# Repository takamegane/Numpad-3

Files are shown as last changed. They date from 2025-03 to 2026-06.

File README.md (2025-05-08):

# Numpad-3
 
## 必要なパーツ
* RP2040 zero x1  
* 1N4148W SMDダイオード x22  
* kailh スイッチソケット(MX用) x19-22  
* 2Uスタビライザー x1  
* cherry MX互換キースイッチ x19-22  
* EC12互換ロータリーエンコーダ x0-3  
* キーキャップ  
* ネオジム磁石 6mm x 3mm x12  
* ポロンスポンジ  
* USB Type-cケーブル x1

## ケースについて
ポロンスポンジを用いたガスケットマウント方式です。  
固定はネオジム磁石で上下のケースを固定しています。 
入手先としてはダイソーで販売がありますのでそちらを購入いただくとよいと思います。

超強力マグネットミニ ８コ入
https://jp.daisonet.com/products/4549131156621
ネオジム磁石はケース接着剤で固定してください。接着剤は少な目で十分です。
一部ハマりにくいところがあるかもしれませんが、やすりで広げるか力を入れればはめ混むことが出来ます。

またガスケットパーツのポロンスポンジは以下で入手出来ます。

Keebox Poron Gasket Strip 32 Gaskets 3mm
https://a.aliexpress.com/_ooY0SvX
こちらは加工不要で貼り付けるだけで使用できます。

もしくはamazon等で販売されている以下のスポンジを加工して貼り付けることで代用可能です。
イノアック ポロンスポンジロール 3tX100mmX1M テープ付 黒 L24-3100MT
https://amzn.asia/d/iE0oSrb
こちらは30mmx3mm程度に切ってスイッチプレートのガスケット部分の両側に貼り付けてください。

## はんだ付けについて
一般的な自作キーボードと作業は同じです。
RP2040 zeroのみ裏表の注意が必要です。
以下のような向きではんだ付けを行ってください。
基板表側にブートスイッチ、リセットスイッチが来る向きで、実装基板の裏側に取り付けます。
rp2040zero
rp2040zero

## ファームウェアについて
vialでキーマップを変更できます。基本的なファームとなっているため、好みに合わせてキーマップを作成しなおしてください。

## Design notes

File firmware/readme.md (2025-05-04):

# numpad3

numpad3

*A short description of the keyboard/project*

* Keyboard Maintainer: [taka](https://github.com/taka)
* Hardware Supported: *The PCBs, controllers supported*
* Hardware Availability: *Links to where you can find this hardware*

Make example for this keyboard (after setting up your build environment):

    make numpad3:default

Flashing example for this keyboard:

    make numpad3:default:flash

See the [build environment setup](https://docs.qmk.fm/#/getting_started_build_tools) and the [make instructions](https://docs.qmk.fm/#/getting_started_make_guide) for more information. Brand new to QMK? Start with our [Complete Newbs Guide](https://docs.qmk.fm/#/newbs).

## Bootloader

Enter the bootloader in 3 ways:

* **Bootmagic reset**: Hold down the key at (0,0) in the matrix (usually the top left key or Escape) and plug in the keyboard
* **Physical reset button**: Briefly press the button on the back of the PCB - some may have pads you must short instead
* **Keycode in layout**: Press the key mapped to `QK_BOOT` if it is available

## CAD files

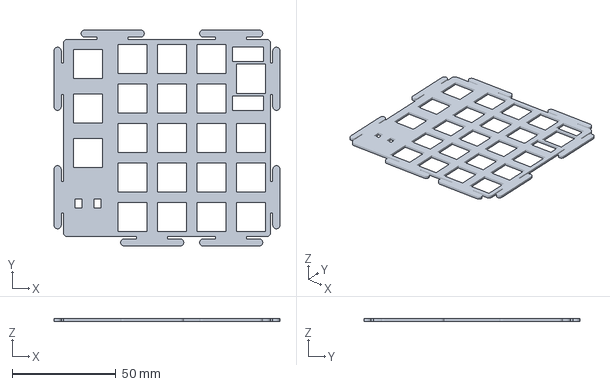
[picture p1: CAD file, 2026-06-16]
plate data/plate.3mf
109.0 x 104.2 x 1.50 mm

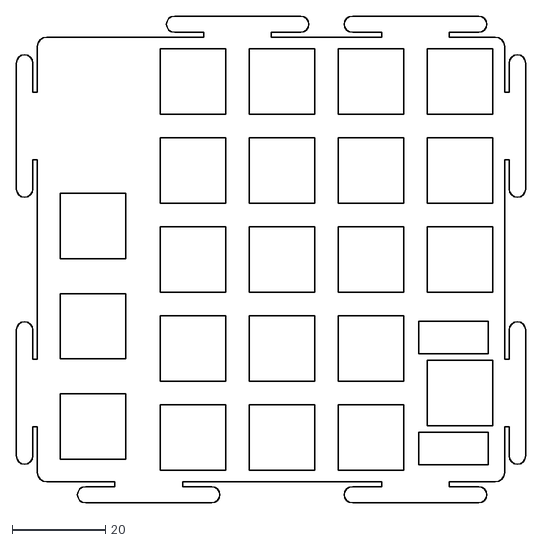
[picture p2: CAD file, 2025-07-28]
plate data/Numpad+3-Edge_Cuts.dxf
109.0 x 104.2

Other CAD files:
plate data/bottomplate.f3d

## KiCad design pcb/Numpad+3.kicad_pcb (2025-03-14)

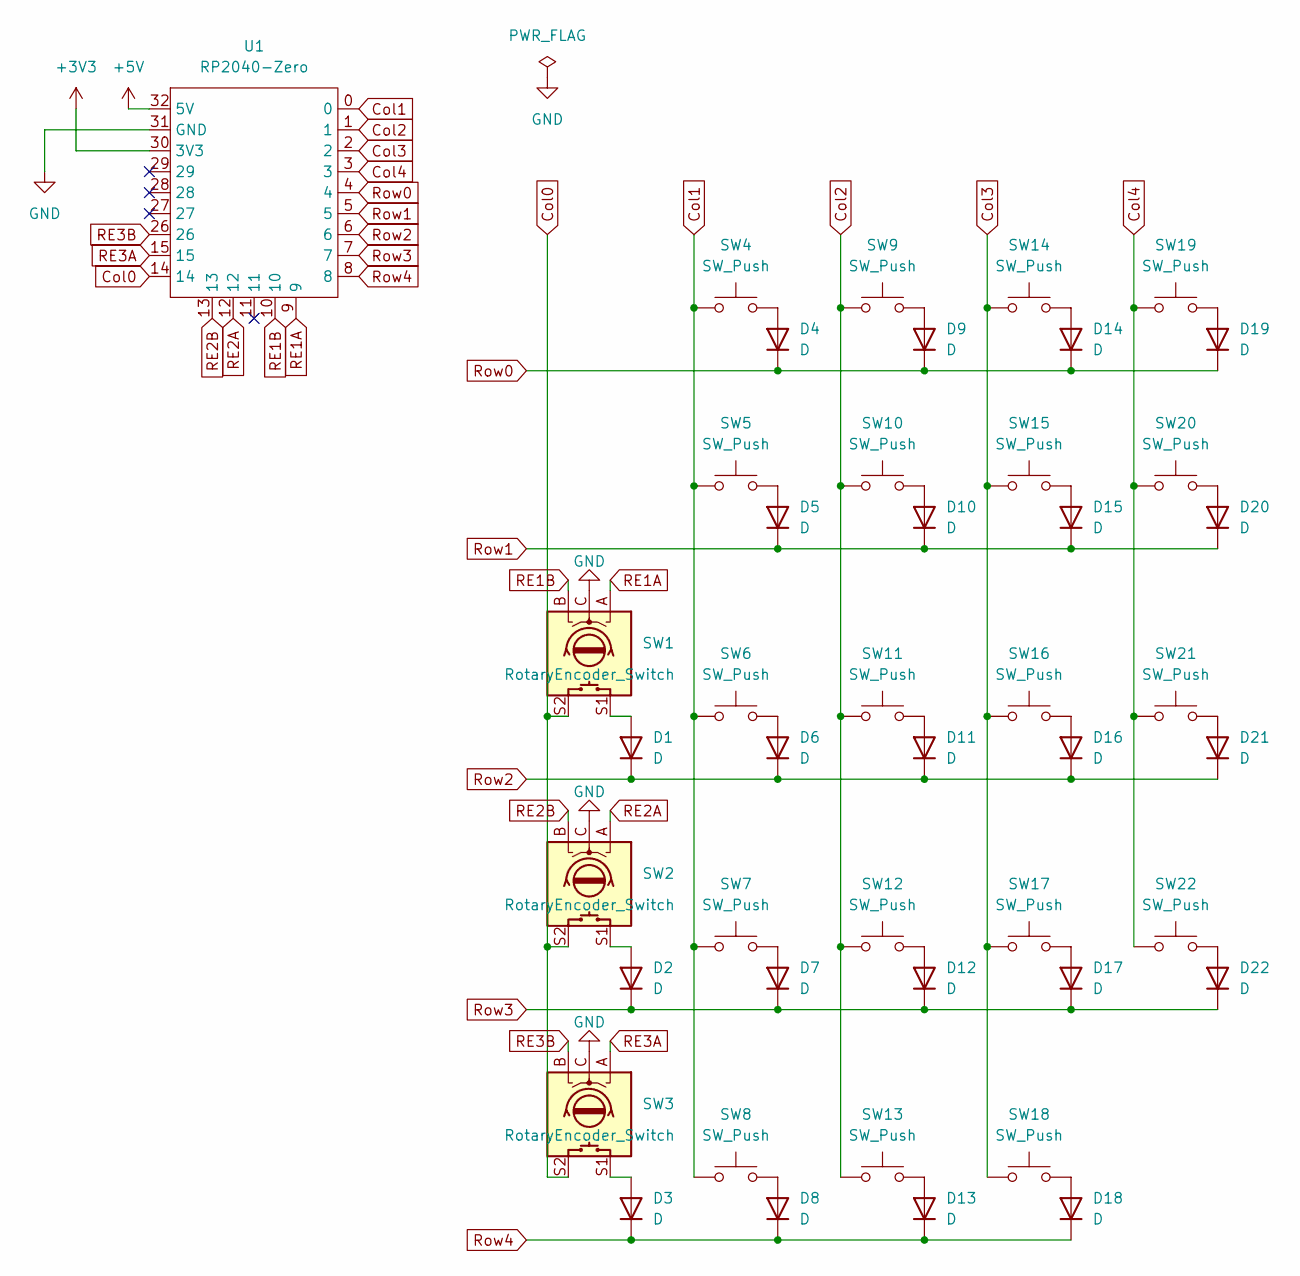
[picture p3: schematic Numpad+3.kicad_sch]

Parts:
D1, D2, D3, D4, D5, D6, D7, D8, D9, D10, D11, D12, D13, D14, D15, D16, D17, D18, D19, D20, D21, D22: D; Diode_SMD
SW1, SW2, SW3: RotaryEncoder_Switch; MX1U_Hotswap+RE
SW4, SW5, SW6, SW7, SW8, SW9, SW10, SW11, SW12, SW13, SW14, SW15, SW16, SW17, SW18, SW19, SW20, SW21: SW_Push; MX1U_Hotswap
SW22: SW_Push; MX2U_Hotswap
U1: RP2040-Zero; RP2040 Zero_fix

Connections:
+3V3: U1.30 (3V3)
+5V: U1.32 (5V)
Col0: SW1.S2, SW2.S2, SW3.S2, U1.14
Col1: SW4.1, SW5.1, SW6.1, SW7.1, SW8.1, U1.0
Col2: SW9.1, SW10.1, SW11.1, SW12.1, SW13.1, U1.1
Col3: SW14.1, SW15.1, SW16.1, SW17.1, SW18.1, U1.2
Col4: SW19.1, SW20.1, SW21.1, SW22.1, U1.3
GND: SW1.C, SW2.C, SW3.C, U1.31 (GND)
unnamed: D1.2 (A), SW1.S1
unnamed: D2.2 (A), SW2.S1
unnamed: D3.2 (A), SW3.S1
unnamed: D4.2 (A), SW4.2
unnamed: D5.2 (A), SW5.2
unnamed: D6.2 (A), SW6.2
unnamed: D7.2 (A), SW7.2
unnamed: D8.2 (A), SW8.2
unnamed: D9.2 (A), SW9.2
unnamed: D10.2 (A), SW10.2
unnamed: D11.2 (A), SW11.2
unnamed: D12.2 (A), SW12.2
unnamed: D13.2 (A), SW13.2
unnamed: D14.2 (A), SW14.2
unnamed: D15.2 (A), SW15.2
unnamed: D16.2 (A), SW16.2
unnamed: D17.2 (A), SW17.2
unnamed: D18.2 (A), SW18.2
unnamed: D19.2 (A), SW19.2
unnamed: D20.2 (A), SW20.2
unnamed: D21.2 (A), SW21.2
unnamed: D22.2 (A), SW22.2
RE1A: SW1.A, U1.9
RE1B: SW1.B, U1.10
RE2A: SW2.A, U1.12
RE2B: SW2.B, U1.13
RE3A: SW3.A, U1.15
RE3B: SW3.B, U1.26
Row0: D4.1 (K), D9.1 (K), D14.1 (K), D19.1 (K), U1.4
Row1: D5.1 (K), D10.1 (K), D15.1 (K), D20.1 (K), U1.5
Row2: D1.1 (K), D6.1 (K), D11.1 (K), D16.1 (K), D21.1 (K), U1.6
Row3: D2.1 (K), D7.1 (K), D12.1 (K), D17.1 (K), D22.1 (K), U1.7
Row4: D3.1 (K), D8.1 (K), D13.1 (K), D18.1 (K), U1.8

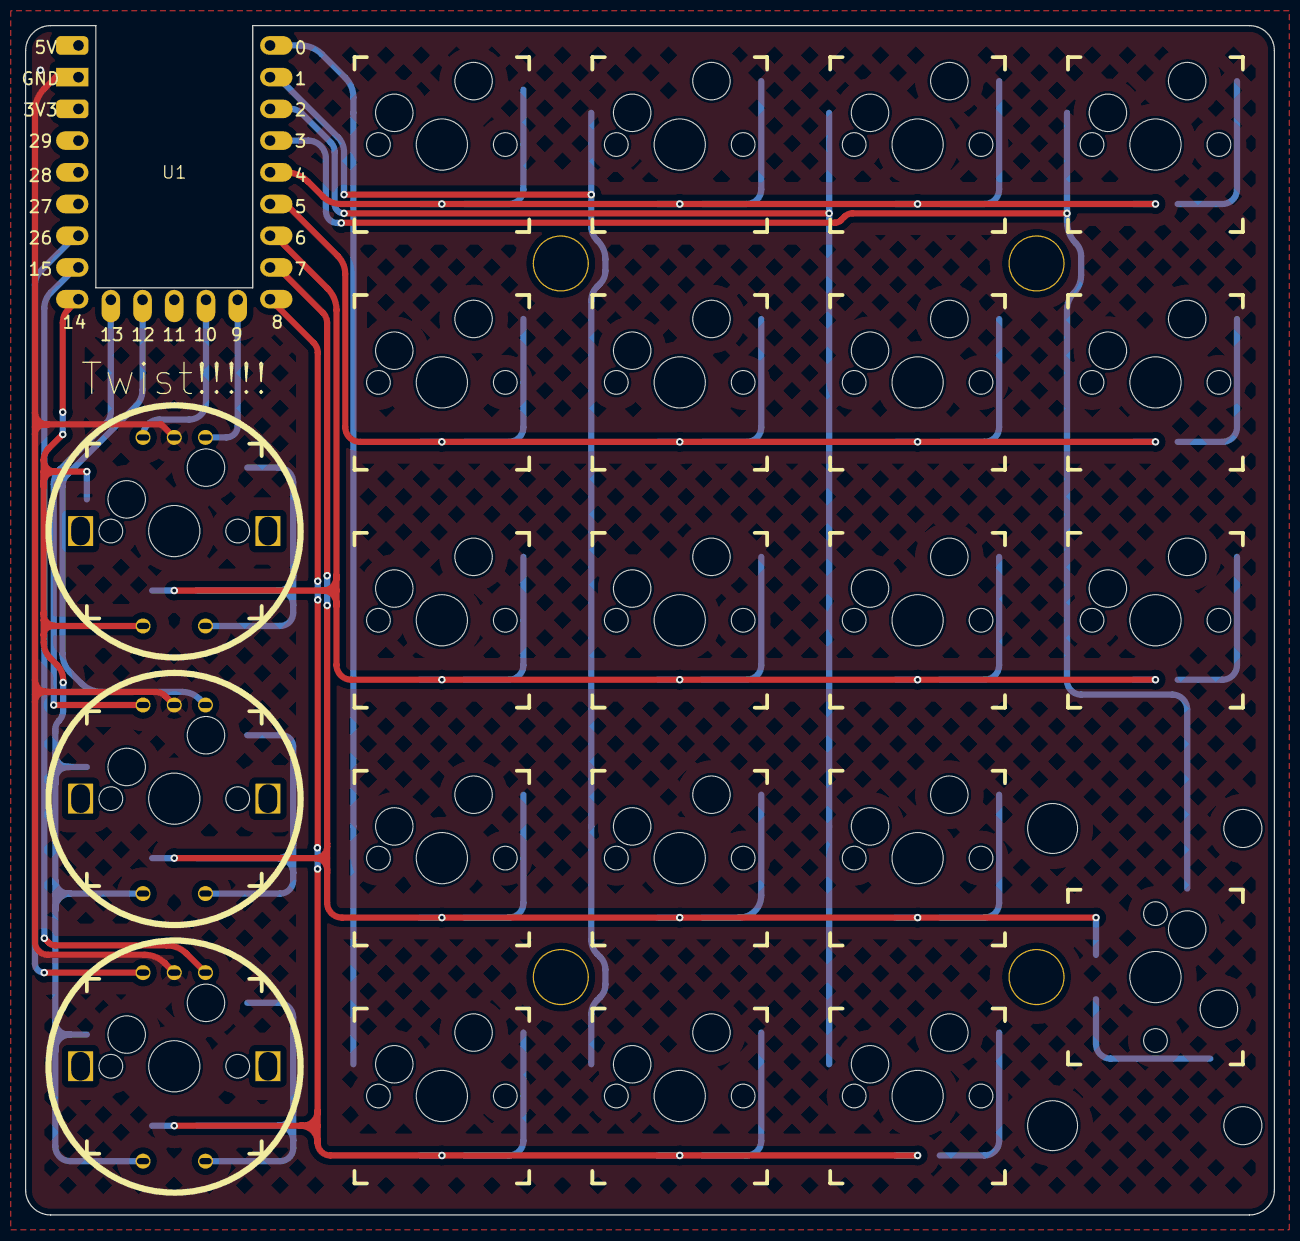
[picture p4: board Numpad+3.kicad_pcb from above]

Board: 2 copper layers, 100.0 x 95.2 mm, 49 parts (0 on the bottom side), 39 nets.

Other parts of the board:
Ref**: Val**; m2_Spacer_Hole
Ref**#2, Ref**#3, Ref**#4: Val**; m2_Spacer_Hole

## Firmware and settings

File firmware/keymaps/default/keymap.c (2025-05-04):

// Copyright 2023 QMK
// SPDX-License-Identifier: GPL-2.0-or-later

#include QMK_KEYBOARD_H

    const uint16_t PROGMEM keymaps[][MATRIX_ROWS][MATRIX_COLS] = {
    [0] = LAYOUT(
                                KC_NUM,         KC_PSLS,        KC_PAST,        KC_BSPC,
                                KC_P7,          KC_P8,          KC_P9,          KC_PMNS,
                KC_B,           KC_P4,          KC_P5,          KC_P6,          KC_PPLS,      
                KC_C,           KC_P1,          KC_P2,          KC_P3,          KC_PENT,
                KC_A,           KC_P0,          KC_P0,          KC_PDOT
    ),
    [1] = LAYOUT(
                                KC_NUM,         KC_PSLS,        KC_PAST,        KC_BSPC,
                                KC_P7,          KC_P8,          KC_P9,          KC_PMNS,
                KC_B,           KC_P4,          KC_P5,          KC_P6,          KC_PPLS,      
                KC_C,           KC_P1,          KC_P2,          KC_P3,          KC_PENT,
                KC_A,           KC_P0,          KC_P0,          KC_PDOT  
    ),
    [2] = LAYOUT(
                                KC_NUM,         KC_PSLS,        KC_PAST,        KC_BSPC,
                                KC_P7,          KC_P8,          KC_P9,          KC_PMNS,
                KC_B,           KC_P4,          KC_P5,          KC_P6,          KC_PPLS,      
                KC_C,           KC_P1,          KC_P2,          KC_P3,          KC_PENT,
                KC_A,           KC_P0,          KC_P0,          KC_PDOT
    ),
    [3] = LAYOUT(
                                KC_NUM,         KC_PSLS,        KC_PAST,        KC_BSPC,
                                KC_P7,          KC_P8,          KC_P9,          KC_PMNS,
                KC_B,           KC_P4,          KC_P5,          KC_P6,          KC_PPLS,      
                KC_C,           KC_P1,          KC_P2,          KC_P3,          KC_PENT,
                KC_A,           KC_P0,          KC_P0,          KC_PDOT
    )
};


const uint16_t PROGMEM encoder_map[][NUM_ENCODERS][NUM_DIRECTIONS] = {
    [0] = { ENCODER_CCW_CW(KC_C, KC_D),
            ENCODER_CCW_CW(KC_C, KC_D), 
            ENCODER_CCW_CW(KC_E, KC_F), 
            ENCODER_CCW_CW(KC_G, KC_H), 
            ENCODER_CCW_CW(KC_I, KC_J),
            ENCODER_CCW_CW(KC_G, KC_H) },
    [1] = { ENCODER_CCW_CW(KC_C, KC_D),
            ENCODER_CCW_CW(KC_C, KC_D), 
            ENCODER_CCW_CW(KC_E, KC_F), 
            ENCODER_CCW_CW(KC_G, KC_H), 
            ENCODER_CCW_CW(KC_I, KC_J),
            ENCODER_CCW_CW(KC_G, KC_H) },
    [2] = { ENCODER_CCW_CW(KC_C, KC_D),
            ENCODER_CCW_CW(KC_C, KC_D), 
            ENCODER_CCW_CW(KC_E, KC_F), 
            ENCODER_CCW_CW(KC_G, KC_H), 
            ENCODER_CCW_CW(KC_I, KC_J),
            ENCODER_CCW_CW(KC_G, KC_H) },
    [3] = { ENCODER_CCW_CW(KC_C, KC_D),
            ENCODER_CCW_CW(KC_C, KC_D), 
            ENCODER_CCW_CW(KC_E, KC_F), 
            ENCODER_CCW_CW(KC_G, KC_H), 
            ENCODER_CCW_CW(KC_I, KC_J),
            ENCODER_CCW_CW(KC_G, KC_H) },
};
